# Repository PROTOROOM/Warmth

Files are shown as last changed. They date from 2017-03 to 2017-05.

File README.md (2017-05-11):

# Warmth
The lighting place card for YoungJi & Derrick's wedding
  - PROTOROOM 
  - by SeungBum Kim & Hoonida Kim
  - 2017.04.01
  
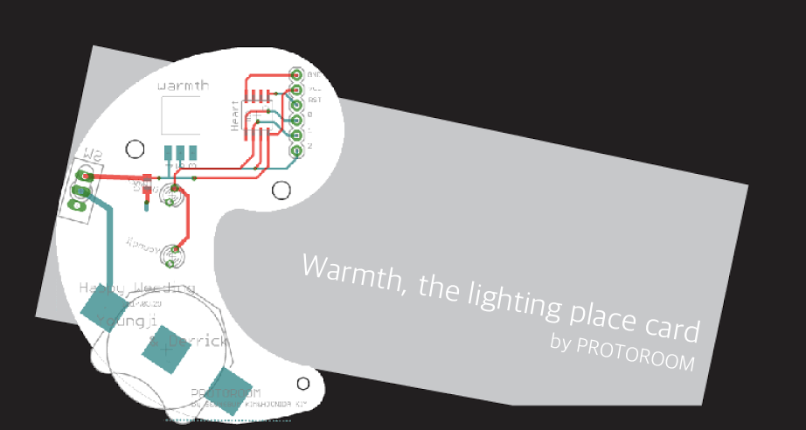
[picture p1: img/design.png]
design v1.2


이 프로젝트의 이야기는 다음 웹페이지에서 읽어볼 수 있습니다.
Please read the whole story of Warmth on the link below. (sorry for Korean only now)

https://protoroom.github.io/Warmth/memo/story_of_warmth.html

# License
 - firmware : Artistic License 2.0
 - hardware : Creative Commons Attribution ShareAlike 3.0

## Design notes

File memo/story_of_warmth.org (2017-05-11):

#+TITLE: Story of Warmth
#+SUBTITLE: The wedding device for Young Ji & Derrick
#+AUTHOR: PROTOROOM
#+HTML_HEAD: <link rel="stylesheet" href="css/tufte.css" type="text/css" />
#+OPTIONS: toc:1

* Warmth is

Warmth는 2017년 4월 1일 영지와 데릭의 결혼[fn:wedding] 을 축복해주기 위해 PROTOROOM이 만든 장치입니다.
결혼식 후 보스턴 과학 박물관에서 진행된 리셉션에서 하객들을 위한 Place Card[fn:pcard]로 사용이 되었습니다.
아크릴에 각인된 하객의 이름이 LED에 의해 빛이 나며 따뜻한 입김을 불어 넣으면 박동하는 장치입니다.

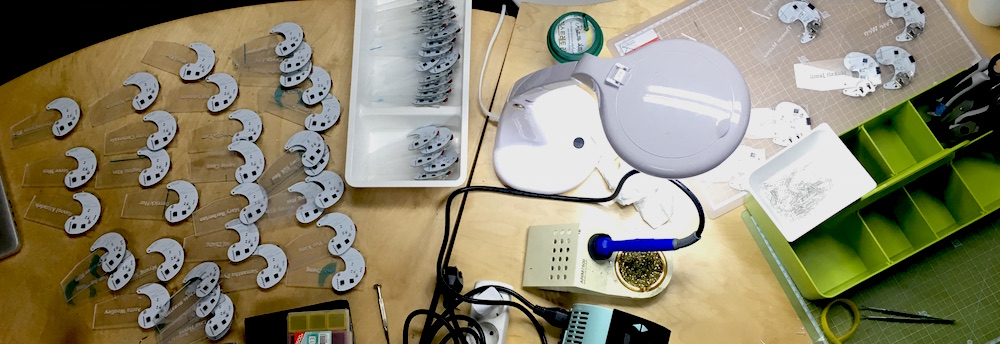
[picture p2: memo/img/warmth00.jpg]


  - 제작 : PROTOROOM (SeungBum Kim & Hoonida Kim)
  - 여러 친구들의 조언과 도움이 함께 했습니다. :)
    
[fn:wedding] http://derrick-youngji.com

[fn:pcard] 미국의 결혼식에서는 리셉션 자리가 따로 있군요. 하객들이 앉아야 할 자리에 이름표를 붙여주는 데
이를 Place Card라고 부릅니다.

* 이야기의 시작
PROTOROOM의 김승범에게는 여동생 영지가 있습니다. 오랜 시간 미국에서 유학생활을 했고,
이제는 데릭을 만나 새로운 인생의 출발을 하게 되었습니다. 동생이지만 삶의 동료로서 PROTOROOM을 
항상 지지해주고 관심을 가져주는 영지를 위해 PROTOROOM의 후니다 킴과 김승범은 기억에 남는 선물을 마련했습니다.

리셉션의 장소가 보스턴 과학 박물관인지라, 그리고 영지도 어떤 geek한, 그리고 PROTOROOM의 작업으로
어울릴만한 무언가가 있으면 좋겠다는 생각을 계속 해왔습니다. 몇 가지 엉뚱한 아이디어[fn:ideas]들이 오고 갔지만
최종적으로 상호작용이 있는 Place Card로 좁혀지게 되었습니다.

최종적으로 영지와 데릭은 새로운 Place Card로써 몇 가지 요구사항을 던져주었습니다.
- Place Card의 원래 기능에 충실해야 함, 이름이 잘 보여야함
- 70여명의 하객
- 테이블 위에 세울 수 있어야 함
- 3D 프린터나 레이저컷 등등 뭔가 geek한 특징이 있으면 좋겠음 :)
- 하객들에게 일종의 기념 선물이 되면 좋겠음

[fn:ideas] PROTOROOM이 앞으로 실험하게 될 작품의 Building Block을 쌓는다는 느낌으로 RF 기반의 사람들 간에
상호작용을 일으킬 수 있는 장치를 만들어볼까 생각도 했습니다만 사전 테스팅 없이 처음 가는 장소에서 실험하기에는 
무리가 있다 판단을 했습니다. 

* Dirty Sketches
PROTOROOM은 컴퓨팅 매체에 대한 어떤 개념들을 담기 위해 하드웨어와 소프트웨어를 이용한 키트를
만들어왔습니다. 이번처럼 리셉션 이벤트의 Place Card라는 구체적인 목적을 충족시키는 작업은 처음인데요,
일정상 3D 프린터 기반보다는 아크릴컷을 기본 형태로 가기로 했고, 따뜻한 인터렉션을 만들 수 있는 
무언가를 생각하게 되었습니다.

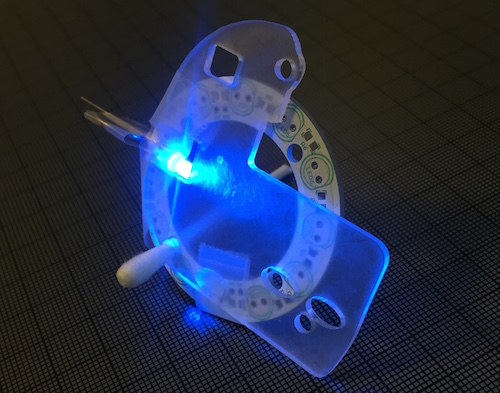
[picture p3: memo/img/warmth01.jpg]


기존에 작업실에 있던 아크릴 조각과 예전에 후니다님이 제작한 PCB, 집에 굴러다니는 면봉으로
Place Card 더티 하드웨어 스케치를 해봤습니다. 대충 개념적으로 이런 모습이 되면 전자 장치 기반의
Place Card가 되지 않을까?하고요.

* 실험과 프로토타이핑
** 아크릴 실험
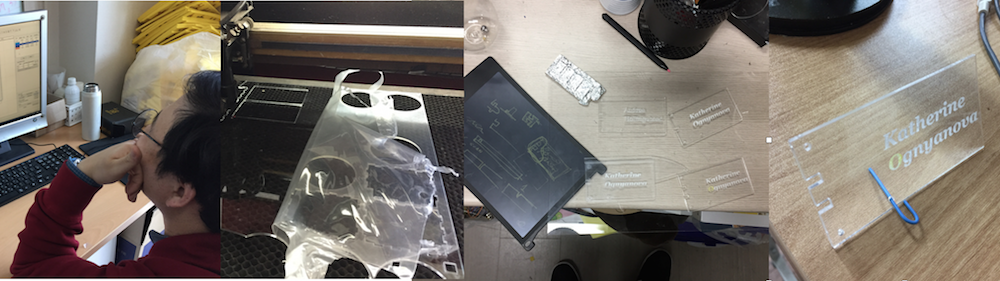
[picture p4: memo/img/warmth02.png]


아크릴 커팅 실험을 위해 헬로긱스의 강병수 소장님이 큰 도움을 주셨습니다.
아크릴 표면을 새기기 위한 적당한 레이저컷 세팅을 함께 실험해주었고, 
최종 아크릴 가공도 헬로긱스에서 할 수 있도록 배려해주었습니다. 

** PCB 조각
PCB 디자인에는 공기 조각가이자 PCB 조각가(?)이신 후니다님이 큰 역할을 해주었습니다.
덕분에 저는 SW개발, 재료 및 일정 관리 등에 더 집중할 수 있었죠.
  
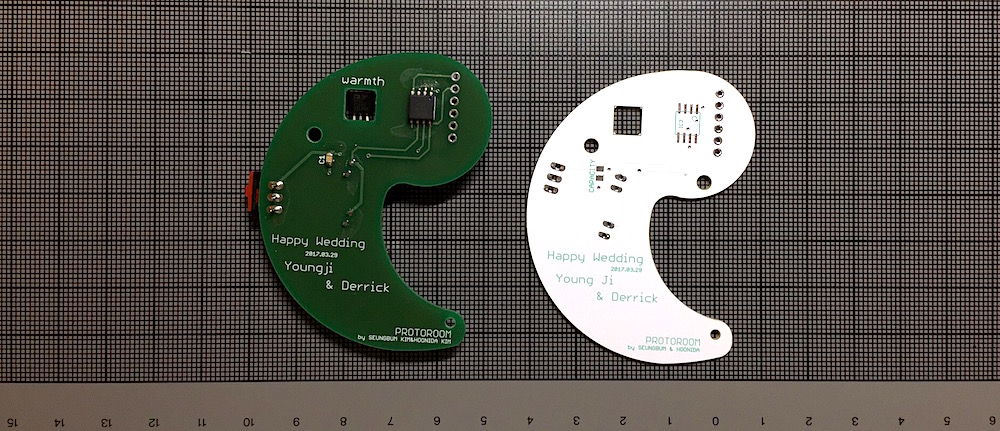
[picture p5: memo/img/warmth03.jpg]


샘플을 먼저 만들어 테스팅 후 세부적인 수정을 해서 최종 흰색 바탕에 녹색 실크가 들어간 PCB가 만들어졌습니다.

디자인은 전통적인 악세사리인 '곡옥[fn:ok]'에서 영감을 받았습니다. 

[fn:ok] 그 의미를 조금 더 찾아보니 태극 문양의 원형이었다는 말도 있고, 
'다산(?)'의 의미도 있어서 이번 작업에 어울린다는 생각을 했습니다. :)

* 재료의 수급
Warmth를 제작하기 위해 다음과 같은 핵심 재료들이 사용되었습니다.

** PCB
    항상 한샘디지텍[fn:hsdgt]에 맡기고 있습니다. 간단하게 샘플을 만들 때에는 좀 비싸다는 느낌도 있지만 
    결과물이 확실하고, 주문하는 과정에서 발생할 수 있는 문제에 대해서도 적극 대응해줍니다.

[fn:hsdgt] http://hsdgt.com

** ATtiny85 10SU 
    tiny [fn:tiny] 칩은 아두이노 기반의 작은 장치를 만들 때 애용하고 있습니다.
    대량 구매를 해서 단가를 낮출 수 있었는데, 요새는 그래도 가격대가 많이 올라가서 아쉽습니다.
    자주 써오던 20XX에 비해 10XX이 낮은 전압에서도 동작해서 이번에 선택했는데 어느정도의 차이가 날지는 좀 더 살펴봐야겠습니다.

[fn:tiny]  ATtiny85 10SU smd 타입. 네, 손으로 납땜할만합니다. ^^

** TMP36
    온도센서 [fn:tmp36] 입니다. 너무 비쌉니다. 
    구로에서 좀 싸지 않을까 발품 팔아봤지만 부품도 안보이고, 그나마 있는 곳은 역시 비싸더군요.
    일부만 구매하고 인터넷으로 나머지를 좀 더 싸게 주문했습니다.
    헬로긱스의 병월님도 이거 너무 비싸다고 thermistor를 쓰는게 더 좋지 않겠냐 조언해주었지만,
    이번에는 디자인 상 이걸로 하기로 했습니다.
    대체 부품으로 LM35가 저렴하긴했는데 동작 전압에서 좀 차이를 보이는거 같아 더 이상 테스팅은 안했습니다.

[fn:tmp36]  모양이 트렌지스터처럼 생긴 녀석이에요. 비싸지만 모양이 Warmth랑 어울려서 썼습니다.

** LED
    아크릴을 밝게 비추기 위해서 어떤게 좋을지 더 실험이 필요했는데,
    이번에는 3mm 라운드타입 고휘도 LED 2개를 사용했습니다. 

** CR2032배터리와 smd타입의 배터리소켓
    가장 흔하게 쓰는 코인 배터리이지만 아쉽게도 항공기 안에 가지고 들어갈 수가 없습니다.
    작년 일본 ICC에 키트를 가져갈 때에도 겪은 문제로 혹시라도 포장한 여러 키트에 넣고 갈 경우
    엄청 고생할 수 있는 부분이죠. 이번엔 동생이 따로 미국에서 구매를 해야했네요.

    smd타입의 배터리 소켓은 예상했던 것 보다도 납땝하기가 번거로웠습니다. 
    납땜 부위가 넓어서인지 납이 고르게 잘 붙지 않았고,
    PCB에서 - 극을 연결이 되도록 추가로 얇게 납을 발라야하는 일도 있었죠.

** 아크릴
    을지로에서 압출식 아크릴을 원판으로 구매를 했습니다. 일반 구매보다 가격이 저렴하다 생각은 했지만,
    레이저컷을 실험해보면서 아크릴마다 각인 시에 레이저 파워에 따라 글자 주변이 흉하게 녹는게 발생하더군요.
    나중에 다시 작업한다면 아크릴을 몇 종류 더 테스트해봐야겠습니다.

** PC 투명 나사와 너트
    폴리카보네이트(PC) 나사와 너트 [fn:bolt] 는 후니다님이 잘 사용하셔서 이번에도 적용했습니다.
    을지로와 구로에서 나사와 너트를 구매했는데 보기보다 가격이 꽤 나가는 재료입니다.
    특히 국산과 일본산의 품질 차이가 좀 있다고 하는데, 을지로에서 산 너트는 품질이 좀 균일하지 않았습니다.
    반면 구로에서 산 국산 너트는 부드럽게 나사에 잘 들어가서 앞으로는 여기 제품을 이용해야겠습니다.

[fn:bolt]  폴리카보네이트 나사와 너트. 저 작은 너트 하나가 50원이야!!!

** Maped Big color clip 
   Warmth를 세우기 위해 지지대로 사용한 크기가 큰 컬러클립 [fn:clip] 입니다. 지지대를 새롭게 설계하기 보다는
   기존의 제품을 이용해서 쉽게 만들자고 생각했고, 예전에 구매했던 재료 중에 하나를 사용하게 되었습니다.
   그러나 이 녀석이 생각치도 못한 복병이었습니다. 이 재료에 맞게 설계를 마치고 제작을 시작한 후에
   정작 Maped의 빅클립은 구할 수가 없었습니다. 서울 이곳 저곳을 찾으러 돌아다니다가 (체력과 시간을 꽤 소모했죠)
   결국은 아마존에서 주문해서 미국에서 제품을 받아 마무리했습니다. 
   개인적으로는 큰 교훈을 얻었는데, 사소한 부품 하나라도 재고파악을 정확히 해야하겠습니다. 미리미리.

[fn:clip]  왜 이런 문구류는 판매주기가 짧을까요. 이제 한국에서 구하기 힘든거 같아요.

* 제작 & 친구들의 도움
** 헬로긱스 점령
아크릴 커팅을 위해 헬로긱스가 큰 도움을 주었습니다. 

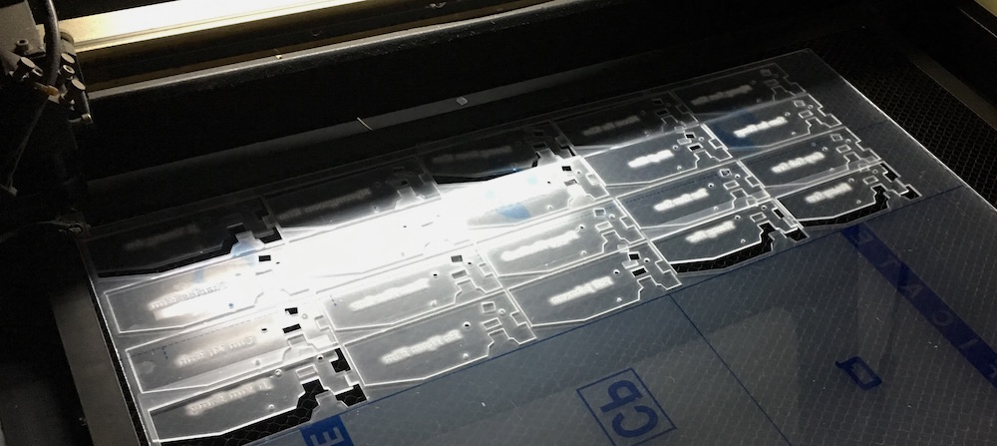
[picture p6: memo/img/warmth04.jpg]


레이저커터와 사무실을 저희에게 맡겨주시고 모두 퇴근하셨죠. :)
각 아크릴 판마다 이름을 달리 새겨야하는 부분이 좀 번거로웠지만 (전세 낸?) 레이저커터 덕분에
여유를 갖고 제작을 완료할 수 있었습니다.

** 수작업 납땜, 조립, 프로그래밍
모든 장치는 수작업으로 납땜과 조립을 했습니다. 

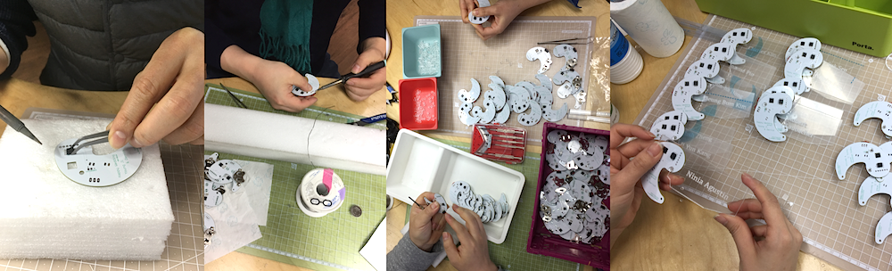
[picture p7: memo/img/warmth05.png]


여분을 포함해서 75개 정도를 만들어야했는데, 부품 수가 적어서 3명의 인력으로 이틀에 나눠 작업할 수 있었습니다.

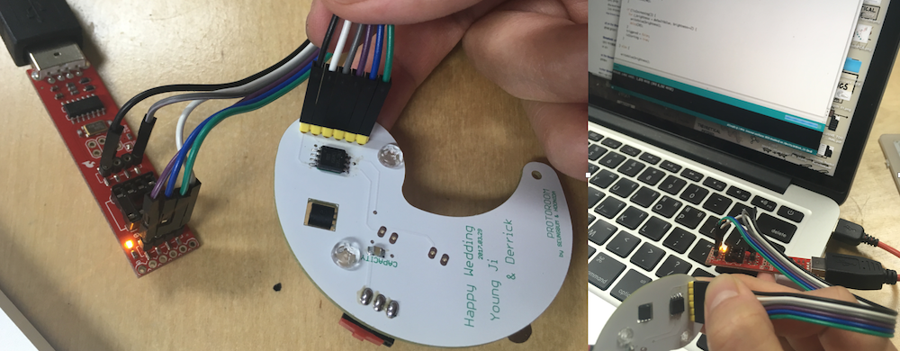
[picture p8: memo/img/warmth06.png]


아두이노와 USBTinyISP[fn:isp]를 이용해서 ATtiny85에 펌웨어를 업로딩했습니다.
ISP 커넥터를 1x6 배열을 사용하면 별다른 커넥터 부품을 쓰지 않고 핀을 기울이듯 연결하면 큰 무리없이 업로딩이 가능합니다.

[fn:isp] https://www.sparkfun.com/products/11801

* 설치와 퍼포먼스
MIT 채플에서의 결혼식 후, 리셉션은 보스턴 과학 박물관에서 진행이 되었습니다.
초대된 하객들을 위한 Place Card가 입구에 세팅이 되었고, 입장과 함께 자신의 이름이 적힌 장치를 손에 들었습니다.

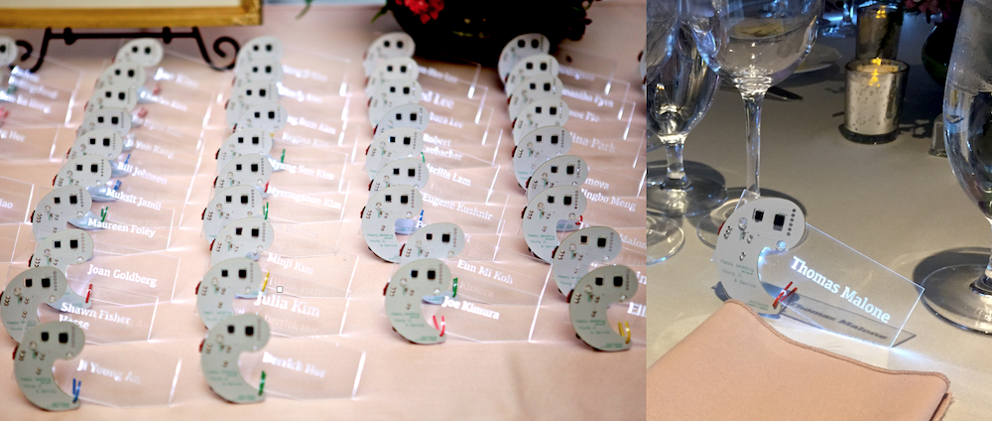
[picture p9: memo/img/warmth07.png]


대부분의 하객들이 이 생소한 장치에 깊은 관심을 보였으며, 덕분에 여러 대화를 나눌 수 있었습니다.
숨어 있는 기능에 대해서는 말을 아꼈는데, 몇몇 장치들은 실내의 온도 변화로 반짝거려서 사람들의 궁금증은 더 커졌습니다.

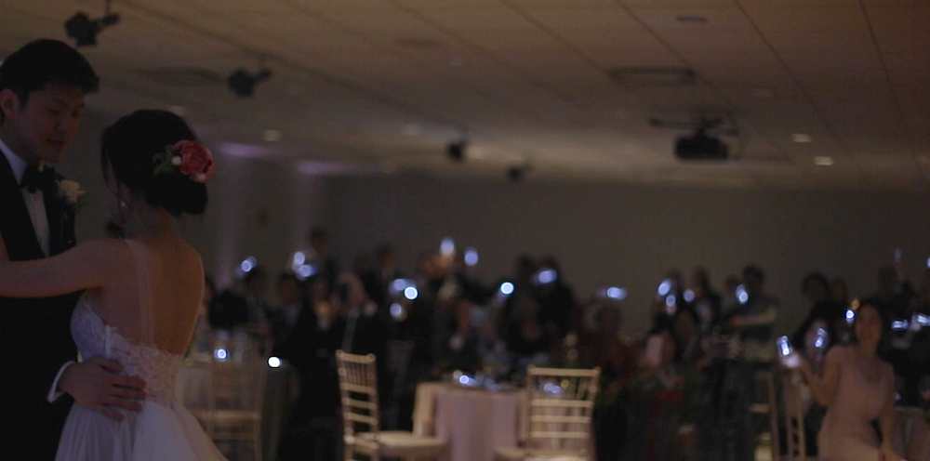
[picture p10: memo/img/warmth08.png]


웨딩 리셉션의 하이라이트인 신랑 신부의 댄스가 시작이 되고, 사회를 맡았던 DJ는 warmth장치에 따뜻한 입김을 불어넣으며
반짝거리는 빛과 함께 두 사람을 축복해달라고 멘트를 날립니다.

한쪽에는 밤 하늘의 찰스강이 흐르고 있고, 다른 쪽에서는 반딧불처럼 warmth가 박동하면서 환상적인 장면을 연출하였습니다.

* 설계도와 소스코드
영지와 데릭의 결혼을 축복하고자 만든 PROTOROOM의 Warmth는 오픈소스로 공개를 합니다.



저장소는 다음과 같으며, 펌웨어 코드는 Artistic License 2.0 [fn:art] 을 하드웨어 회로와 기타 자료에
대해서는 Creative Commons Attribution ShareAlike 3.0 [fn:cc] 라이선스를 따릅니다.

- https://github.com/PROTOROOM/Warmth
  
기타 Warmth 프로젝트와 관련된 문의사항은 PROTOROOM으로 부탁드립니다.

- Warmth, the lighting place card.
- by [[http://protoroom.kr][PROTOROOM (SeungBum Kim & Hoonida Kim)]]

[fn:art] https://choosealicense.com/licenses/artistic-2.0 개인적으로 좋아하는 라이선스입니다.
코드에서의 시적허용이라니, 너무 멋지지 않나요?

[fn:cc] https://creativecommons.org/licenses/by-sa/3.0/legalcode

* 도움을 주신 분들
Warmth가 만들어지기까지 크고 작은 도움을 주신 분들입니다. 감사합니다. :)

 - 헬로긱스 : 레이저커터를 지원해주셨습니다.
   - 강병수 : 레이저커터 셋업 및 아크릴 제작을 위한 도움을 주셨습니다.
   - 김병월 : 프로토타이핑 시의 부품 및 기술적 디자인에 대한 조언을 주셨습니다.
 - 정다운 : 장치 납땜 및 조립을 도와주셨습니다.
 - 김은지 : 장치 지지대 부품 제작을 도와주셨습니다.
 - 박동희 : 하드웨어 부품 관련 조언을 주셨습니다.

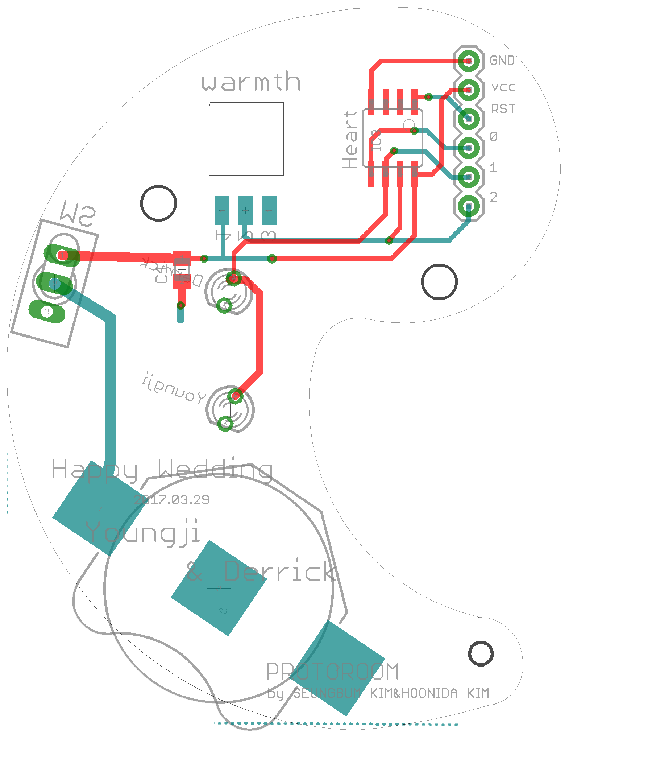
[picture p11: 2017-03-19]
hardware/ATTINY-warmthV1.2/반달V1.2.png

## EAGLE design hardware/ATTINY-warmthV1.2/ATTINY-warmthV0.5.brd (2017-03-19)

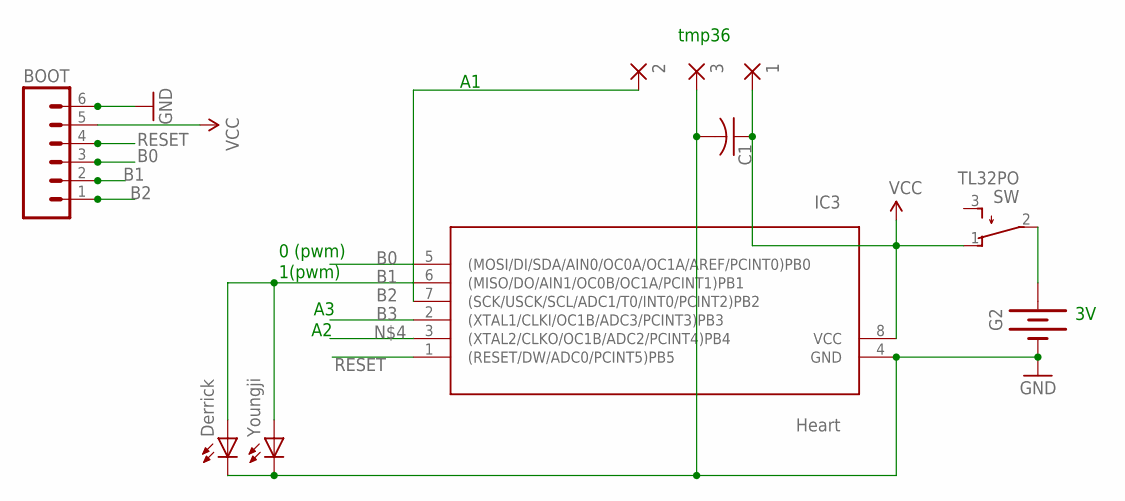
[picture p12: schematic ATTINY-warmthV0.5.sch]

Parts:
1, 2, 3: WIREPADSMD1,27-254; SMD1,27-2,54
BOOT: M06SIP; 1X06
C1: C-USC0805K; C0805K
G2: BATTERY20SMD; BATTCON_20MM
IC3: Heart; SOIC8
SW: TL32PO; TL3XPO
TX: Derrick; LED3MM
TX1: Youngji; LED3MM

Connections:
B0: BOOT.3, IC3.5 ((MOSI/DI/SDA/AIN0/OC0A/OC1A/AREF/PCINT0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)
B1: BOOT.2, IC3.6 ((MISO/DO/AIN1/OC0B/OC1A/PCINT1)PB1), TX.A, TX1.A
B2: 2.1, BOOT.1, IC3.7 ((SCK/USCK/SCL/ADC1/T0/INT0/PCINT2)PB2)
B3: IC3.2 ((XTAL1/CLKI/OC1B/ADC3/PCINT3)PB3)
GND: 3.1, BOOT.6, C1.2, G2.2 (-), IC3.4 (GND), TX.K (C), TX1.K (C)
unnamed: G2.1 (+), SW.2
RESET: BOOT.4, IC3.1 ((RESET/DW/ADC0/PCINT5)PB5)
VCC: 1.1, BOOT.5, C1.1, IC3.8 (VCC), SW.1 (O)

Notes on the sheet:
1(pwm)
0 (pwm)
tmp36

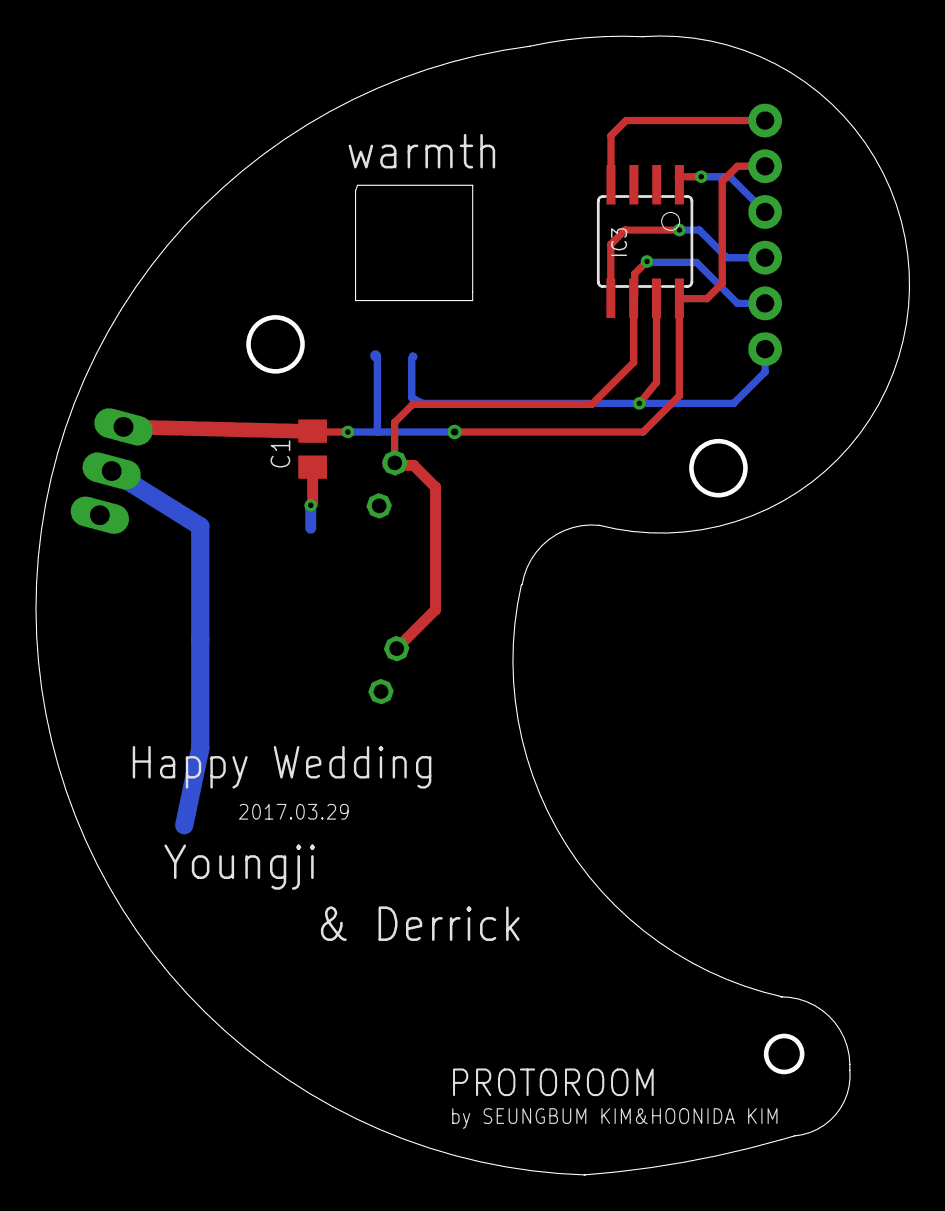
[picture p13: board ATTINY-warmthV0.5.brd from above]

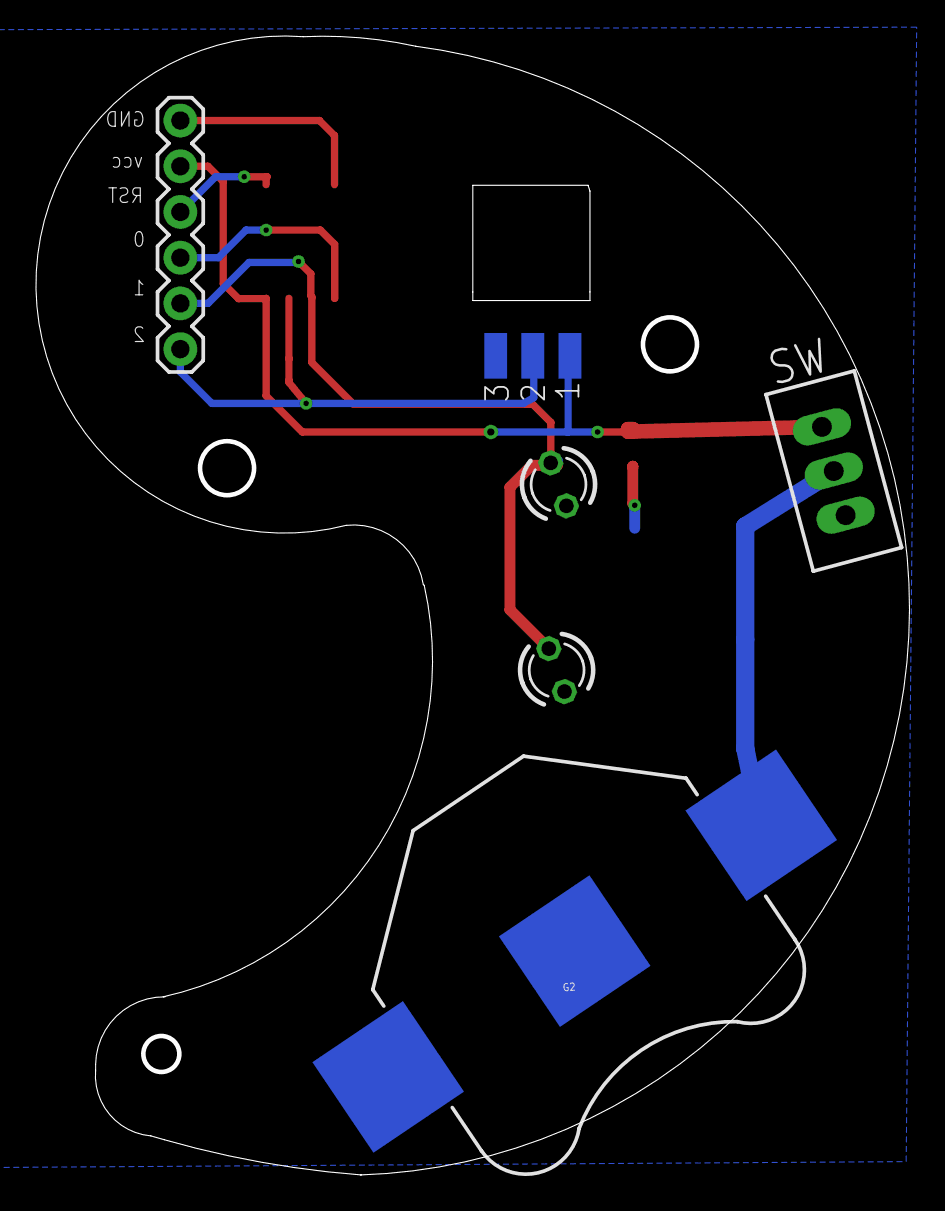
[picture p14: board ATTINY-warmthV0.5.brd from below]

Board: 2 copper layers, 48.5 x 63.3 mm, 10 parts (8 on the bottom side), 7 nets.

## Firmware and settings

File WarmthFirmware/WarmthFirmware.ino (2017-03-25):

/*
	# Warmth : light device for warmth
 - https://github.com/PROTOROOM/Warmth
 	- by SeungBum Kim & Hoonida Kim
 	- Artistic License 2.0  http://choosealicense.com/licenses/artistic-2.0/
 	
 */

int analogInput = A1;
int analogOutput = 1;

const int numReadings = 50;
int readings[numReadings];
int readIndex = 0;
int total = 0;
int average = 0;
int current = 0;
int oldTemp = 0;

boolean triggered = false;
boolean isStarting = true;

long pTime = 0;
long cTime = 0;
int fade = 20;
int brightness = 0;
int pulseCount = 0;
int minValue = 0;
int defaultValue = 130;
int threshold = 5;

void setup() {                
  pinMode(analogOutput, OUTPUT);

  averageTemp(1);
  brightness = defaultValue;
}


// ##########################  MAIN  ##########################
void loop() {

  current = readSmooth();
  cTime = millis();


  if (triggered) {
    
    if (isStarting) {
      for (;brightness<256;brightness+=1) {
        writeValue(brightness);
        delay(10);
      }
      delay(1000);      
      isStarting = false;
    }

    for (int i=0; i<5; i++) {
      beatPulse2(40);
    }
    
    if (!isIncreasing()) {
      for (;brightness < defaultValue; brightness+=2) {
        writeValue(brightness);
        delay(20);
      }    
      triggered = false;
      isStarting = true;
    }

  } else {
    
    writeValue(brightness);
    
    if ((current - average) > threshold && isIncreasing()) {
      triggered = true;
      pulseCount = 0;
    }

  }

}


// ##########################  Commands  ##########################
boolean isIncreasing() {
  boolean result = false;
  if (cTime - pTime > 200) {
    pTime = cTime;
    if (current > oldTemp) result = true;
    oldTemp = current;
  }
  
  return result;
}


void beatPulse(int beat) {  
  if (brightness <= 0) {
    fade = 20;
  }
  if (brightness >= 255) {
    fade = -5;
    pulseCount++;
  }

  if (cTime - pTime > int(1000/beat)) {
    pTime = cTime;
    writeValue(brightness);
    brightness = brightness + fade;
  }
}


void beatPulse2(int beat) {
//  brightness = 0;
  for (;brightness<=255;brightness+=10) {
    writeValue(min(255, brightness));
    delay(1000/beat);
  }
  for (;brightness>minValue; brightness-=5) {
    writeValue(brightness);
    delay(1000/beat);
  }
}


void averageTemp(boolean withLight) {
  int t = 0;
  int n = 30;
  for (int i=0; i<n; i++) {
    t = t + analogRead(analogInput);

    if (withLight) {
      if (n%2 == 0) writeValue(100);
      else writeValue(0);
    }

    delay(100);
  }
  average = t / n;
}


int readSmooth() {
  total = total - readings[readIndex];
  readings[readIndex] = analogRead(analogInput);
  total = total + readings[readIndex];
  readIndex = readIndex + 1;
  
  if (readIndex >= numReadings) readIndex = 0;
  return total / numReadings;
}


// Analog Input
int readValue() {
  return map(analogRead(analogInput), 0, 1023, 0, 255);
}


float readTemp() {
  int reading = analogRead(analogInput);
  float voltage = reading * 3.0/1024.0;
  //  float cTemp = (voltage - 0.5) * 100;
  //  return cTemp;
  return voltage;
  //  return map(cTemp, 20, 32, 0, 255);
}

int calibrateLightSensor(int light) {
  int mid = 600;
  int mid2 = 900;
  if ( light < mid) {
    light = int(round((40.0/mid)*light));
  } 
  else if (light < mid2) {
    light = int(round((mid2-40)/(mid2-float(mid))* light) - 1680);
  }
  light = constrain(light, 0, 1023);    
  return light;
}


// Analog Output
void writeValue(int value) {
  analogWrite(analogOutput, value);
}

void slowOn(float waitSec) {
  for (int i=0; i<=255; i=i+5) {
    writeValue(i);
    wait(waitSec);
  }
}

void slowOff(float waitSec) {
  for (int i=255; i>=0; i=i-5) {
    writeValue(i);
    wait(waitSec);
  }	
}



// Common
void wait(float sec) {
  delay(sec*1000);
}

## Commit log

2017-03-19 add hardware
    [ATTINY-warmthV0.5.brd, ATTINY-warmthV0.5.sch]
2017-05-11 add circuit image

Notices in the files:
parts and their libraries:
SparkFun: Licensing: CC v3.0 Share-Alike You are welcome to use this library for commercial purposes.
